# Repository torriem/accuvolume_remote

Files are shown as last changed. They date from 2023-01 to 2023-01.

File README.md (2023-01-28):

Accuvolume has an external display for reading gallons on the outside, but
sometimes it's nice to have a third display if the machine has more than
one fill port.  And also the stock Panasonic display is pretty small to
read from a distance.  This project decodes a little bit of the MODBUS data
feeding the external display to provide an additional display using the
Adafruit 1" 7 segment display backpack.  

RS232 serial data is converted using any RS232 to TTL breakout board based
on a chip like the MAX3232.  Only RX is used, and it's connected to the 
Panasonic HMI, teed into the existing "RD" wire. The RS232 DB9 ground
must be connected to the HMI "-" wire.

I also bring over the 24V "+" wire and use it to power the arduino via a
buck converter to 5v (and GND on the "-" wire).  There's plenty of power
to run this display.  But you can always use any 12V source to power the 
buck converter.

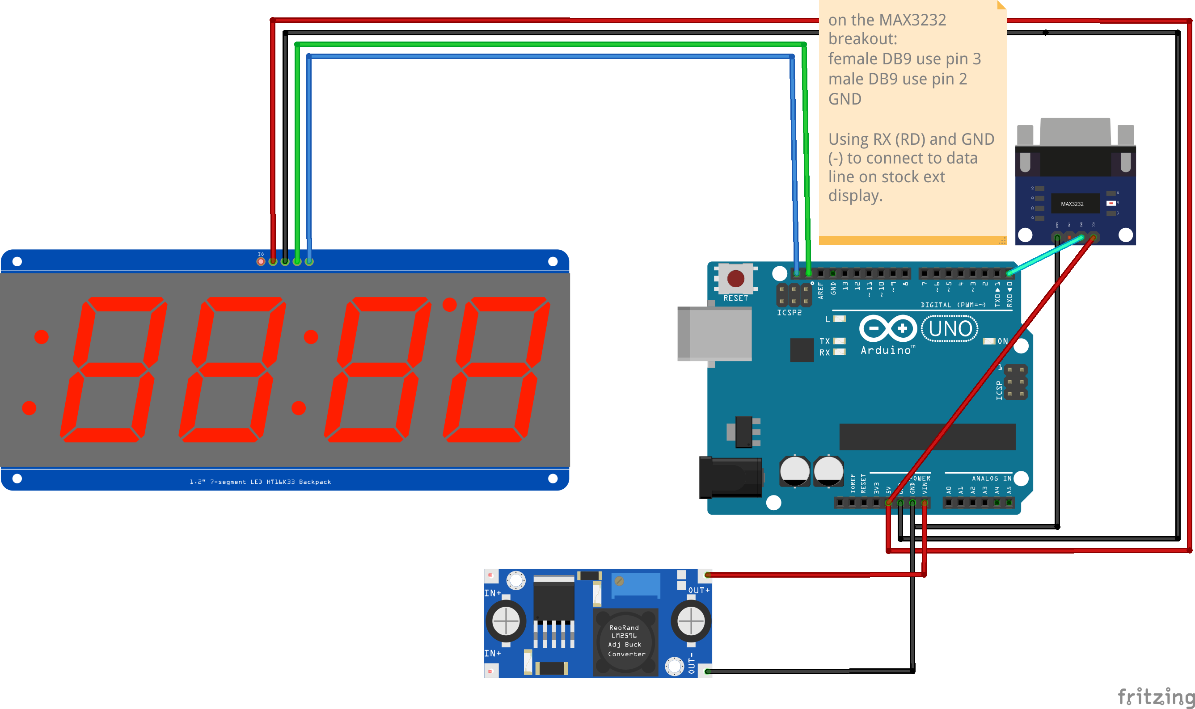
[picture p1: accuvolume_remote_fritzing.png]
frizting diagram


The Accovolume head unit communicates with the in-cab and external Panasonic
HMI screen using a form of MODBUS protocol over RS232.  The speed is 115200
and it's 8 bits, 1 stop bit, ODD parity.  The messages are in plain text
ascii but hex strings.  The messages that seem to have gallons in them look 
like this:

%EE$RD120014

Always the same length, first 4 digits are hex, little endian, gallons. That 
example message is 0x0012, which is 18 gallons.

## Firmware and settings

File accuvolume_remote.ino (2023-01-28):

#include <Wire.h>
#include <Adafruit_GFX.h>
#include <Adafruit_LEDBackpack.h>
#include <EEPROM.h>

/*
 This code intended to run on an Arduino uno or mini
 driving a Adafruit 1.2" 7 segment backpack on i2c.
 */

uint8_t buffer[80];
bool last_rc = false;
Adafruit_7segment matrix = Adafruit_7segment();

unsigned int analogValue7 = 0;
int psi_filtered = 0;

uint8_t hex_to_dec(char d1, char d2) {
	uint8_t value = 0;

	if (d1 >= '0' && d1 <= '9') {
		value = (d1 - '0') << 4;
	} else if (d1 >= 'A' && d1 <= 'F') {
		value = (d1 - 'A' + 10) << 4;
	}

	if (d2 >= '0' && d2 <= '9') {
		value = value + d2 - '0';
	} else if (d2 >= 'A' && d2 <= 'F') {
		value = value + d2 - 'A' + 10;
	}

	return value;
}

struct display
{
  char digits[4];
  unsigned char decimals;
  unsigned char cursor;
} 
display;  // displays be displays

void set_digits(struct display &display, uint16_t number) {
	if (number > 999) { //three digits
		display.digits[0] = number / 1000;
		display.digits[1] = (number / 100) % 10;
		display.digits[2] = (number / 10) % 10;
		display.digits[3] = number % 10;
	} else if (number > 99) { //three digits
		display.digits[0] = number / 100;
		display.digits[1] = (number / 10) % 10;
		display.digits[2] = number % 10;
		display.digits[3] = 'x';
	} else if (number > 9) { //two digits
		display.digits[0] = number / 10;
		display.digits[1] = number % 10;
		display.digits[2] = 'x';
		display.digits[3] = 'x';
	} else { //one digit
		display.digits[0] = number;
		display.digits[1] = 'x';
		display.digits[2] = 'x';
		display.digits[3] = 'x';
	}
}

void setup()
{
	Serial.begin(115200,SERIAL_8O1); //modbus needs odd parity in this case
	//Serial.begin(115200);

	pinMode(A7, INPUT);
	//interrupts();

	delay(1000);
	Serial.println("initializing big display.");
	if(matrix.begin(0x70)) {
		delay(500);
		matrix.print(8888, DEC);
		matrix.writeDisplay();

		delay(500);
		matrix.print(10000, DEC);
		matrix.writeDisplay();

	} else {
		while (1) {
			Serial.println("I2C Error!");
			delay(1000);
		}
	}

	//delay(5000);
	//Serial.println("accuvolume external display.");
	
}

void loop()
{
	uint8_t c = 0;

	uint8_t index = 0;
	uint16_t gallons = 0;

	while (c != '%') { //look for start of message
		if(Serial.available()) {
			c = Serial.read();
		}
	}

	while (c != 13 and index < 79) { //look for end of message
		if(Serial.available()) {
			c = Serial.read();
			buffer[index] = c;
			index++;
		}
	}

	buffer[index] = 0; //terminate
	//Serial.print("buffer is length ");
	//Serial.println((const char *)buffer);
	//Serial.println(index);
	set_digits(display, (uint16_t) index);

	if(index == 12) {
		//we have a packet that's the right length
		//maybe it's what we want.
		if (buffer[4] == 'C') {
			last_rc = true;


		} else if (buffer[4] == 'D') {
			if (last_rc) {
				//last message was an RC message, so this one will be
				//solution tank gallons.
				gallons = hex_to_dec(buffer[7], buffer[8]) << 8;
				gallons += hex_to_dec(buffer[5], buffer[6]);
				Serial.print(gallons);
				Serial.println(" gallons.");
				matrix.print(gallons, DEC);
				matrix.writeDisplay();
				last_rc = false;
			}
		}
	}
}

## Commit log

2022-05-01 decoding solution tank gallons messages now, printing to serial monitor.
2022-10-18 Added parge pressure reading code and support for little 7 segment display.
2022-10-24 removed print outs
2022-10-24 make it work on regular arduino uno for testing.
2022-10-25 final version for arduino pro mini, just with the big adafruit 7 segment display.
2023-01-28 Added Fritzing diagram
    [accuvolume_remote.fzz]
2023-01-28 updated readme, notes in fritzing
    [accuvolume_remote.fzz]
